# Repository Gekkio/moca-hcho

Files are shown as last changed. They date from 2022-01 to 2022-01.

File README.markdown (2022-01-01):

<!--
SPDX-FileCopyrightText: 2021-2022 Joonas Javanainen <joonas.javanainen@gmail.com>

SPDX-License-Identifier: CC0-1.0
-->

# moca-hcho: Bluetooth 5 BLE formaldehyde/temperature/humidity sensor beacon

moca-hcho is a simple Bluetooth Low Energy sensor beacon that uses a [Sensirion SFA30 Formaldehyde Sensor Module](https://www.sensirion.com/en/environmental-sensors/formaldehyde-sensor-sfa30/) to sense formaldehyde/temperature/humidity.
This information is measured and sent periodically using Bluetooth BLE advertisements, which can be received by any Bluetooth 4.0+ device within range.

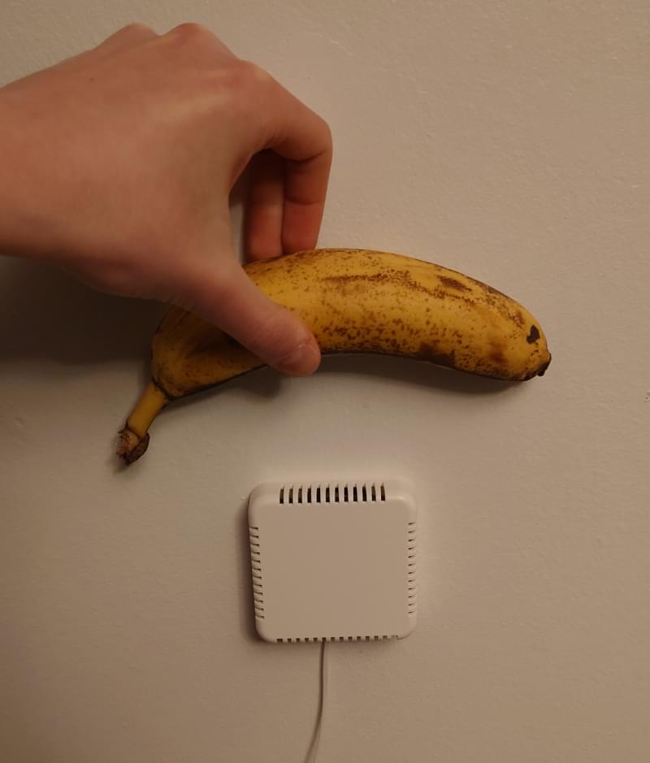
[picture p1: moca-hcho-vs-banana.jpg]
Wall-mounted moca-hcho with banana for scale


Overview:

* Enclosure: Hammond 1551V4WH vented sensor enclosure (wall-mountable)
* Sensor: Sensirion SFA30 Formaldehyde sensor module
* Microcontroller: Fanstel BT832 Bluetooth module with Nordic nRF52832
* Power supply: external +5V power supply
* Firmware (less than 1 kLOC) is written in [Rust](https://www.rust-lang.org/) using the [Embassy embedded async/await framework](https://github.com/embassy-rs/embassy)
* Data is sent periodically using Bluetooth BLE advertisements that are very simple to send and receive
* **Not FCC/Bluetooth/etc certified/qualified** but a "best effort" -style approach is used by using qualified BT832 module with integrated antenna + qualified Nordic S112 SoftDevice Bluetooth stack.

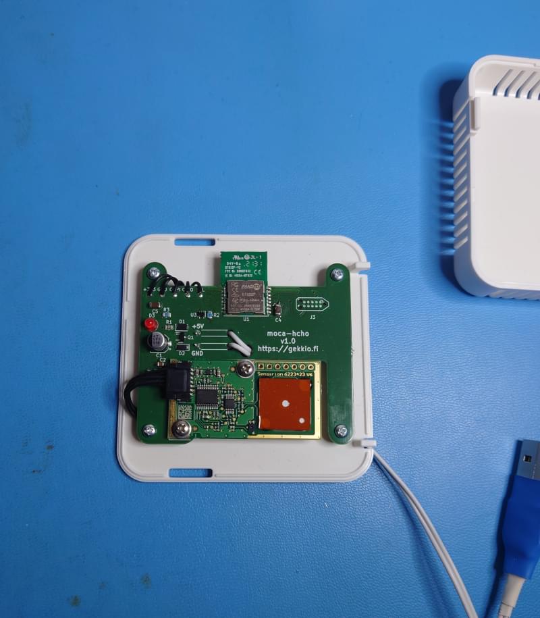
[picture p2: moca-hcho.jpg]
moca-hcho v1.0 assembled, without lid


## Potential future improvements

* Tidy up the code...currently the code is very crude and could use a lot of polish and some tests should be written
* Improve environmental coupling of the sensor. The vented enclosure works fine, but SFA30 Design-In Guide suggests even better environmental coupling options
* Add encryption. Unencrypted advertisements can be read or spoofed by anyone
* Re-evaluate the feasibility of using a battery

## License

Hardware is licensed under Creative Commons Attribution 4.0 International.

Firmware is licensed under either of

 * Apache License, Version 2.0, ([LICENSE-APACHE](LICENSE-APACHE) or http://www.apache.org/licenses/LICENSE-2.0)
 * MIT license ([LICENSE-MIT](LICENSE-MIT) or http://opensource.org/licenses/MIT)

at your option.

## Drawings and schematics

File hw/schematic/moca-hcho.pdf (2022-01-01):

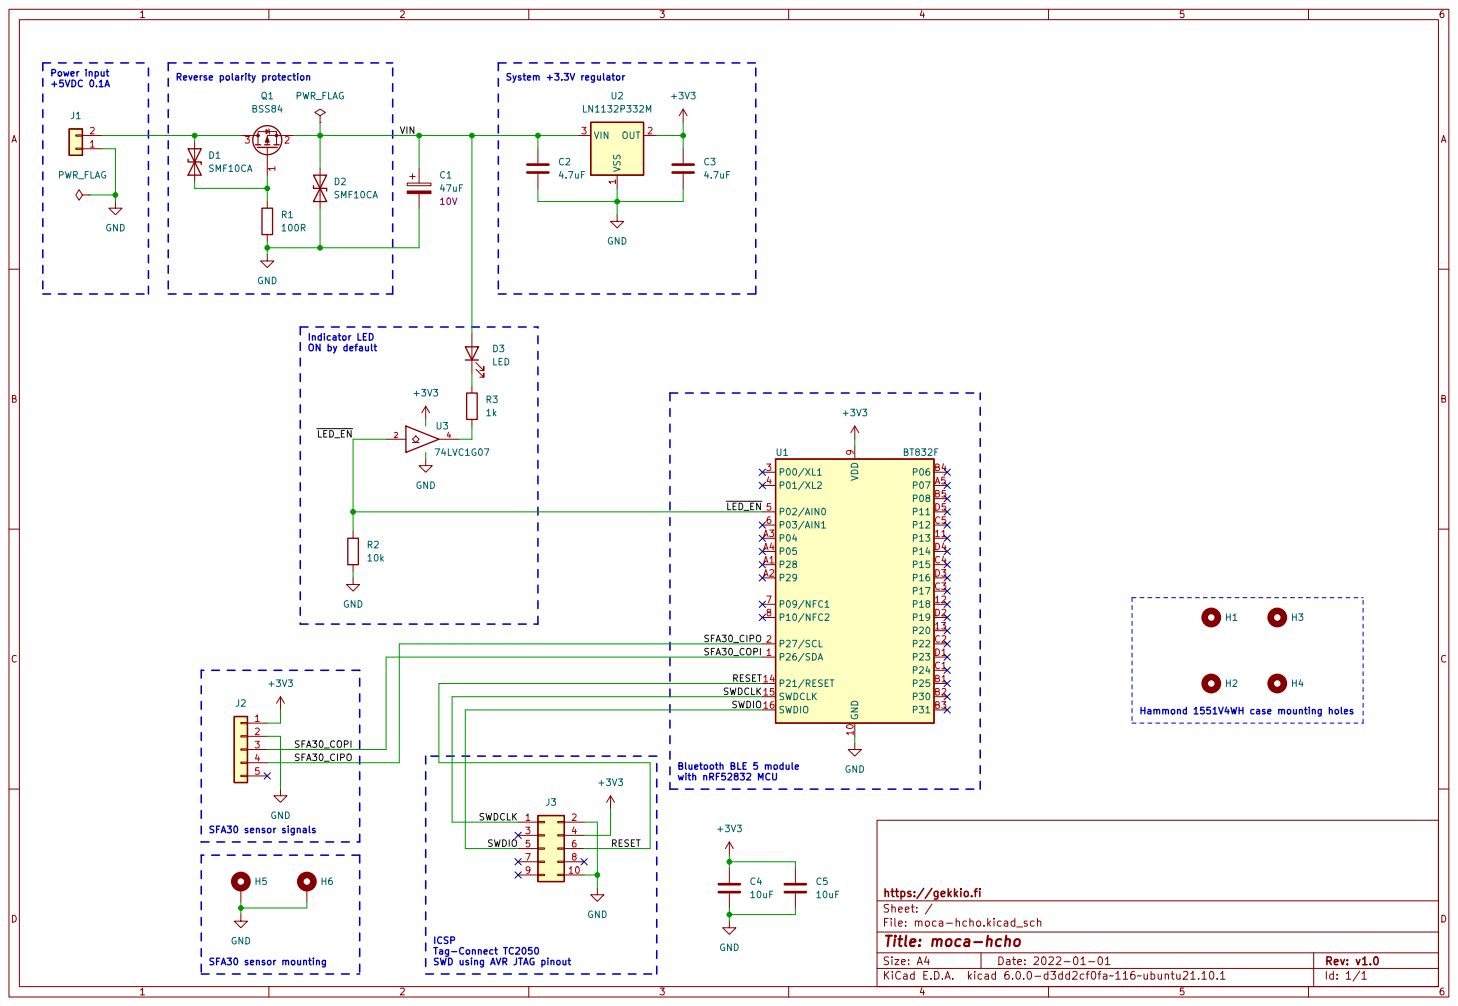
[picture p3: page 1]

System +3.3V regulator Power input +5VDC 0.1A

Indicator LED ON by default

Hammond 1551V4WH case mounting holes

5 | ICSP

File: moca-hcho.kicad_sch Sheet: / https://gekkio.fi H5

Id: 1/1 Title: moca-hcho

Tag-Connect TC2050
SWD using AVR JTAG pinout

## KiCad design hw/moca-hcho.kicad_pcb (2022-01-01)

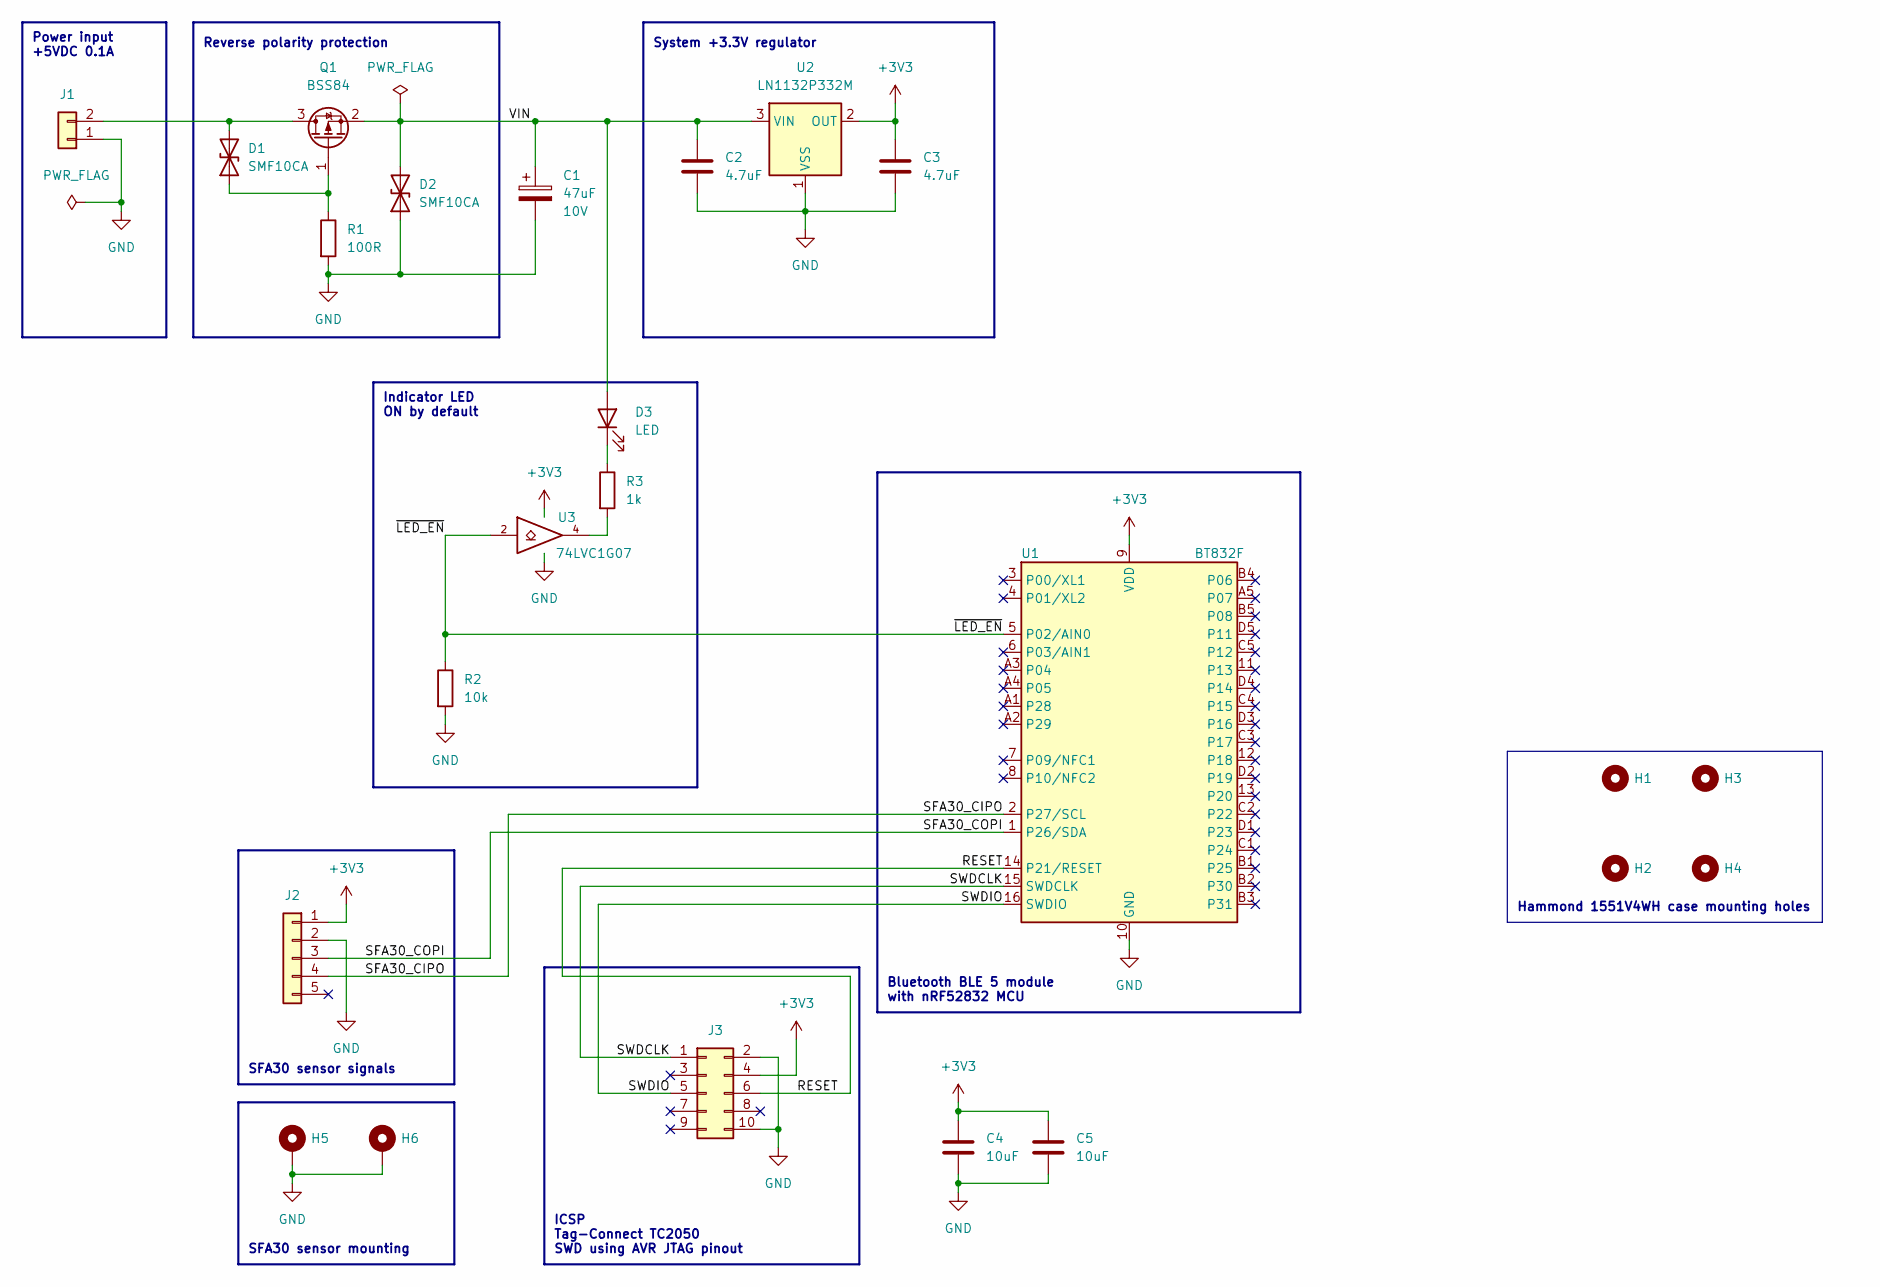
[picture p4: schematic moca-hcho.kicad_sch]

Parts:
C1: 47uF; CP_Elec_5x5.8; Rating 10V
C2, C3: 4.7uF; C_0805_2012Metric
C4, C5: 10uF; C_1206_3216Metric
D1, D2: SMF10CA; D_SOD-123F
D3: LED; LED_D3.0mm
H1, H2, H3, H4: DNP; MountingHole_2.5mm
H5, H6: DNP; MountingHole_2.7mm_M2.5_DIN965_Pad
J1: DNP; SolderWire-0.25sqmm_1x02_P4.2mm_D0.65mm_OD1.7mm_Relief
J2: DNP; SolderWire-0.15sqmm_1x05_P4mm_D0.5mm_OD1.5mm
J3: DNP; Tag-Connect_TC2050-IDC-NL_2x05_P1.27mm_Vertical
Q1: BSS84; SOT-23
R1: 100R; R_0805_2012Metric
R2: 10k; R_0805_2012Metric
R3: 1k; R_0805_2012Metric
U1: BT832F; Fanstel_BT832F
U2: LN1132P332M; SOT-23
U3: 74LVC1G07; SOT-353_SC-70-5

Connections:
+3V3: C3.1, C4.1, C5.1, J2.1, J3.4, U1.9 (VDD), U2.2 (OUT), U3.5 (VCC)
/RESET: J3.6, U1.14 (P21/RESET)
/SFA30_CIPO: J2.4, U1.2 (P27/SCL)
/SFA30_COPI: J2.3, U1.1 (P26/SDA)
/SWDCLK: J3.1, U1.15 (SWDCLK)
/SWDIO: J3.5, U1.16 (SWDIO)
/VIN: C1.1, C2.1, D2.2 (A2), D3.2 (A), Q1.2 (S), U2.3 (VIN)
/~LED_EN: R2.1, U1.5 (P02/AIN0), U3.2
GND: C1.2, C2.2, C3.2, C4.2, C5.2, D2.1 (A1), H5.1, H6.1, J1.1, J2.2, J3.2, J3.10, R1.2, R2.2, U1.10 (GND), U1.A0 (GND), U1.B0 (GND), U1.C0 (GND), U1.D0 (GND), U2.1 (VSS), U3.3 (GND)
unnamed: D1.1 (A1), Q1.1 (G), R1.1
unnamed: D1.2 (A2), J1.2, Q1.3 (D)
unnamed: D3.1 (K), R3.1
unnamed: R3.2, U3.4

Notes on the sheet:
System +3.3V regulator
Indicator LED ON by default
SFA30 sensor mounting
Reverse polarity protection
SFA30 sensor signals
Power input +5VDC 0.1A
Bluetooth BLE 5 module with nRF52832 MCU
Hammond 1551V4WH case mounting holes
ICSP Tag-Connect TC2050 SWD using AVR JTAG pinout

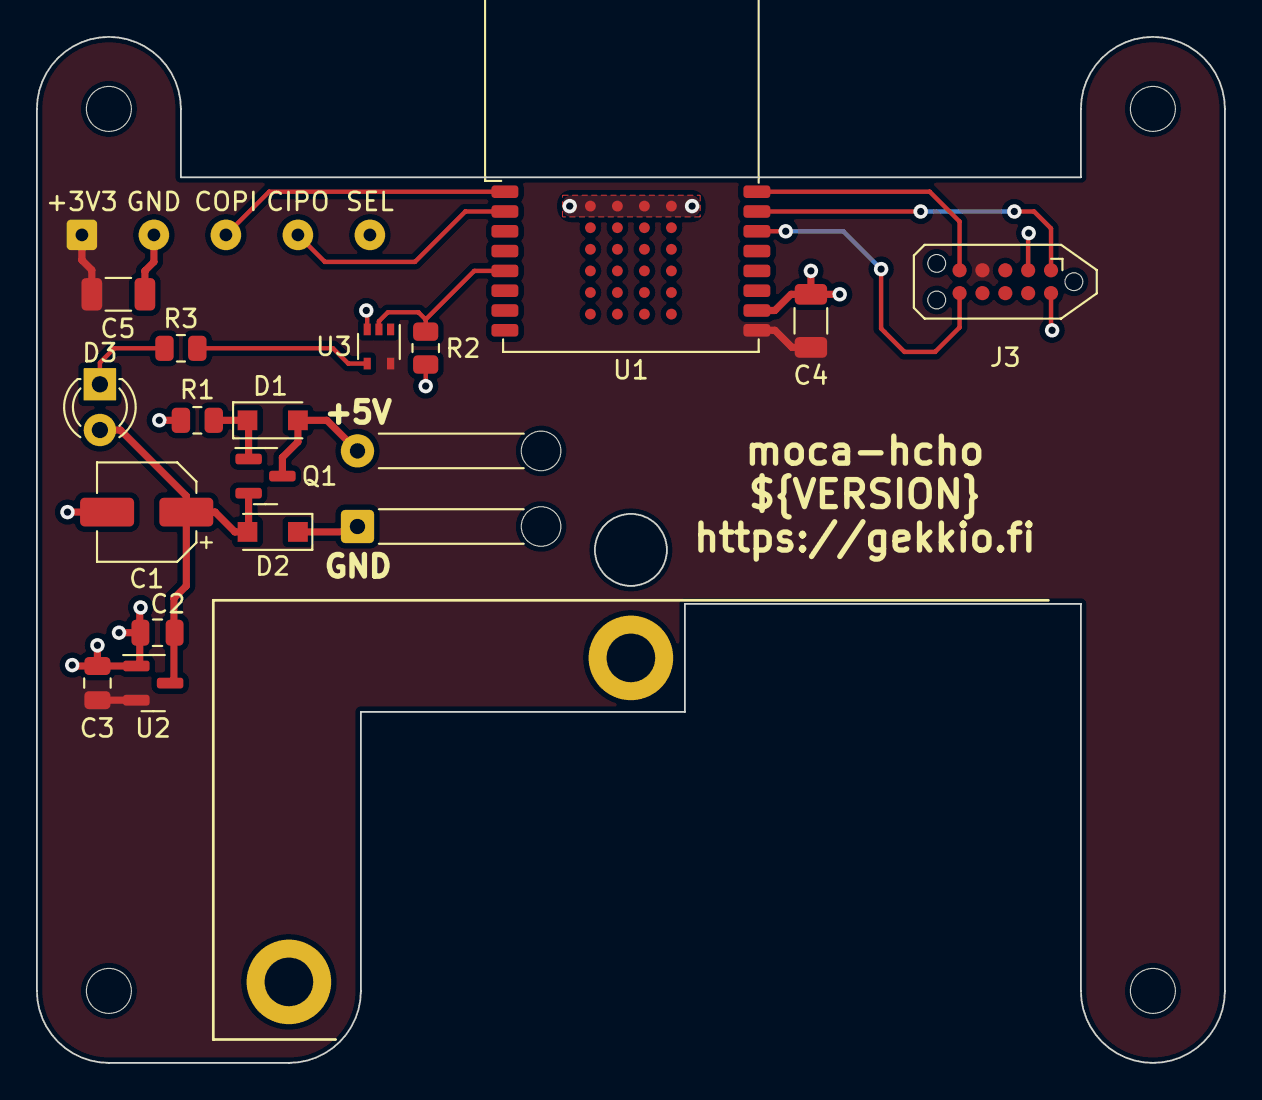
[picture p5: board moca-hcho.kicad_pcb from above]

Board: 2 copper layers, 66.0 x 57.0 mm, 24 parts (0 on the bottom side), 13 nets.

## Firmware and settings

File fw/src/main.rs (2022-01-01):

// SPDX-FileCopyrightText: 2021-2022 Joonas Javanainen <joonas.javanainen@gmail.com>
//
// SPDX-License-Identifier: MIT OR Apache-2.0

#![no_main]
#![no_std]
#![feature(type_alias_impl_trait)]
#![feature(alloc_error_handler)]

extern crate alloc;

use alloc::{string::String, vec::Vec};
use alloc_cortex_m::CortexMHeap;
use core::{
    alloc::Layout,
    borrow::Borrow,
    convert::Infallible,
    sync::atomic::{AtomicUsize, Ordering},
};
use defmt::{debug, error, info, unwrap, Format};
use embassy::{
    executor::{Executor, Spawner},
    time::{Duration, Timer},
    util::Forever,
};
use embassy_nrf::{
    self as _,
    config::HfclkSource,
    gpio::{Level, NoPin, Output, OutputDrive},
    interrupt::{self, Priority},
    peripherals::{P0_02, UARTE0},
    uarte::{self, Uarte},
    Peripherals,
};
use embassy_traits::uart::{Read, Write};
use embedded_hal::digital::v2::{OutputPin, StatefulOutputPin};
use futures::{join, pin_mut};
use moca_hcho::advertising::AdvertisingPayload;
use nrf_softdevice::{
    ble::{
        peripheral::{self, AdvertiseError},
        TxPower,
    },
    raw, Softdevice,
};
use nrf_softdevice_defmt_rtt as _;
use panic_probe as _;

const VENDOR_ID: u16 = 0xffff;
const LED_BLINKER_DURATION: Duration = Duration::from_secs(60 * 5);

#[global_allocator]
static ALLOCATOR: CortexMHeap = CortexMHeap::empty();
const ALLOCATOR_SIZE: usize = 4096;

// define what happens in an Out Of Memory (OOM) condition
#[alloc_error_handler]
fn alloc_error(layout: Layout) -> ! {
    panic!("Failed to allocate {} bytes", layout.size());
}

defmt::timestamp! {
    "{=u64}", {
        static COUNT: AtomicUsize = AtomicUsize::new(0);
        // NOTE(no-CAS) `timestamps` runs with interrupts disabled
        let n = COUNT.load(Ordering::Relaxed);
        COUNT.store(n + 1, Ordering::Relaxed);
        n as u64
    }
}

static EXECUTOR: Forever<Executor> = Forever::new();

#[embassy::task]
async fn softdevice_task(sd: &'static Softdevice) {
    debug!("Starting softdevice");
    sd.run().await;
}

type LedPin = P0_02;

struct Sfa30Buffer {
    data: [u8; 0x100],
    len: usize,
}

impl Default for Sfa30Buffer {
    fn default() -> Self {
        Sfa30Buffer {
            data: [0; 0x100],
            len: 0,
        }
    }
}

impl sfa30::ByteSink for Sfa30Buffer {
    type Error = sfa30::EncodeError;

    fn write_bytes(&mut self, bytes: &[u8]) -> Result<(), Self::Error> {
        self.data[self.len..(self.len + bytes.len())].copy_from_slice(bytes);
        self.len += bytes.len();
        Ok(())
    }
}

impl sfa30::ByteSource for Sfa30Buffer {
    type Error = Infallible;

    fn read_byte(&mut self) -> Result<u8, Self::Error> {
        let byte = self.data[self.len];
        self.len += 1;
        Ok(byte)
    }
}

#[derive(Copy, Clone, Debug, Eq, PartialEq, Format)]
struct Sfa30Measurement {
    hcho_concentration: i16,
    relative_humidity: i16,
    temperature: i16,
}

#[derive(Default)]
struct Sfa30 {
    read_buf: Vec<u8>,
}

impl Sfa30 {
    async fn write_command(
        &mut self,
        uart: &mut Uarte<'_, UARTE0>,
        cmd: u8,
        data: &[u8],
    ) -> Result<(), anyhow::Error> {
        let mut encoder = sfa30::Encoder::new(Sfa30Buffer::default());
        encoder
            .encode_command(cmd, data)
            .map_err(anyhow::Error::msg)?;
        let buf = encoder.finish();
        debug!("SFA W: {:02x}", &buf.data[..buf.len]);

        uart.write(&buf.data[..buf.len])
            .await
            .map_err(|_| anyhow::Error::msg("UART write error"))?;
        Ok(())
    }
    async fn read_response(
        &mut self,
        uart: &mut Uarte<'_, UARTE0>,
    ) -> Result<Vec<u8>, anyhow::Error> {
        self.read_buf.clear();
        self.read_buf.push(0x00);
        uart.read(&mut self.read_buf)
            .await
            .map_err(|_| anyhow::Error::msg("UART read error"))?;

        loop {
            let mut byte = [0x00];
            uart.read(&mut byte)
                .await
                .map_err(|_| anyhow::Error::msg("UART read error"))?;
            self.read_buf.push(byte[0]);
            if byte[0] == 0x7e {
                break;
            }
        }

        debug!("SFA R: {:02x}", &self.read_buf[..]);
        let mut buf = Sfa30Buffer::default();
        buf.data[..self.read_buf.len()].copy_from_slice(&self.read_buf);

        let mut decoder = sfa30::Decoder::new(buf);
        let mut output = Vec::new();
        decoder.decode_to(&mut output).map_err(anyhow::Error::msg)?;
        Ok(output)
    }
    pub async fn reset(&mut self, uart: &mut Uarte<'_, UARTE0>) -> Result<(), anyhow::Error> {
        self.write_command(uart, 0xd3, &[]).await?;
        let _ = self.read_response(uart).await?;
        Ok(())
    }
    pub async fn read_device_marking(
        &mut self,
        uart: &mut Uarte<'_, UARTE0>,
    ) -> Result<String, anyhow::Error> {
        self.write_command(uart, 0xd0, &[0x06]).await?;
        let mut output = self.read_response(uart).await?;
        let _ = output.pop();
        Ok(String::from_utf8(output).map_err(anyhow::Error::msg)?)
    }
    pub async fn start_measurement(
        &mut self,
        uart: &mut Uarte<'_, UARTE0>,
    ) -> Result<(), anyhow::Error> {
        self.write_command(uart, 0x00, &[0x00]).await?;
        self.read_response(uart).await?;
        Ok(())
    }
    pub async fn read_measurement(
        &mut self,
        uart: &mut Uarte<'_, UARTE0>,
    ) -> Result<Sfa30Measurement, anyhow::Error> {
        self.write_command(uart, 0x03, &[0x02]).await?;
        let data = self.read_response(uart).await?;
        Ok(Sfa30Measurement {
            hcho_concentration: i16::from_be_bytes([data[0], data[1]]),
            relative_humidity: i16::from_be_bytes([data[2], data[3]]),
            temperature: i16::from_be_bytes([data[4], data[5]]),
        })
    }
}

#[embassy::task]
async fn async_main(_spawner: Spawner, sd: &'static Softdevice, p: Peripherals) {
    let mut led: Output<LedPin> = Output::new(p.P0_02, Level::Low, OutputDrive::Standard);

    led.set_low().unwrap();

    let mut config = uarte::Config::default();
    config.parity = uarte::Parity::EXCLUDED;
    config.baudrate = uarte::Baudrate::BAUD115200;

    let irq = interrupt::take!(UARTE0_UART0);
    let mut uart = uarte::Uarte::new(p.UARTE0, irq, p.P0_27, p.P0_26, NoPin, NoPin, config);

    info!("uarte initialized!");

    Timer::after(Duration::from_secs(1)).await;

    let mut sfa = Sfa30::default();
    sfa.reset(&mut uart).await.unwrap();
    Timer::after(Duration::from_secs(1)).await;

    info!(
        "SFA30 marking: {}",
        sfa.read_device_marking(&mut uart).await.unwrap()
    );

    let led_timeout = Timer::after(LED_BLINKER_DURATION);
    let led_blinker = async move {
        let _ = led_blinker(led).await;
    };

    pin_mut!(led_timeout);
    pin_mut!(led_blinker);

    let measurement = measurement(sd, uart, sfa);
    let led = futures::future::select(led_timeout, led_blinker);

    join!(led, measurement);
}

async fn led_blinker(mut led: Output<'_, LedPin>) -> Result<(), Infallible> {
    led.set_high()?;
    loop {
        if led.is_set_high()? {
            led.set_low()?;
        } else {
            led.set_high()?;
        }
        Timer::after(Duration::from_millis(1000)).await;
    }
}

async fn measurement(sd: &'static Softdevice, mut uart: Uarte<'_, UARTE0>, mut sfa: Sfa30) {
    sfa.start_measurement(&mut uart).await.unwrap();

    loop {
        let tx_power = TxPower::ZerodBm;
        Timer::after(Duration::from_millis(10_000)).await;

        let meas = sfa.read_measurement(&mut uart).await.unwrap();
        debug!("Raw measurement: {:?}", meas);

        let mut packet = AdvertisingPayload::default();

        unwrap!(packet.push_ad_flags(raw::BLE_GAP_ADV_FLAGS_LE_ONLY_GENERAL_DISC_MODE as u8));
        unwrap!(packet.push_complete_name("moca-hcho"));
        unwrap!(packet.push_tx_power(tx_power));

        let mut custom = [0x00; 0x06];
        custom[0..2].copy_from_slice(&meas.hcho_concentration.to_be_bytes());
        custom[2..4].copy_from_slice(&meas.relative_humidity.to_be_bytes());
        custom[4..6].copy_from_slice(&meas.temperature.to_be_bytes());

        unwrap!(packet.push_manufacturer_data(VENDOR_ID, &custom));

        let config = peripheral::Config {
            max_events: Some(1),
            tx_power,
            ..Default::default()
        };
        let data: &[u8] = packet.borrow();
        let adv = peripheral::NonconnectableAdvertisement::NonscannableUndirected {
            adv_data: packet.borrow(),
        };
        match peripheral::advertise(sd, adv, &config).await {
            Ok(_) | Err(AdvertiseError::Timeout) => (),
            Err(err) => error!("{:?}", err),
        }

        debug!("BLE advertisement done");
    }
}

fn init_hal() -> Peripherals {
    let mut config = embassy_nrf::config::Config::default();
    config.hfclk_source = HfclkSource::ExternalXtal;
    config.gpiote_interrupt_priority = Priority::P7;
    config.time_interrupt_priority = Priority::P2;
    embassy_nrf::init(config)
}

fn enable_softdevice() -> &'static Softdevice {
    const CLOCK_SOURCE: u8 = raw::NRF_CLOCK_LF_SRC_RC as u8;
    const CALIBRATION_INTERVAL_4S: u8 = 16; // unit = 1/4 of seconds
    const TEMP_CALIBRATION_INTERVAL: u8 = 2; // unit = calibration intervals
    const CLOCK_ACCURACY: u8 = raw::NRF_CLOCK_LF_ACCURACY_500_PPM as u8;

    let config = nrf_softdevice::Config {
        clock: Some(raw::nrf_clock_lf_cfg_t {
            source: CLOCK_SOURCE,
            rc_ctiv: CALIBRATION_INTERVAL_4S,
            rc_temp_ctiv: TEMP_CALIBRATION_INTERVAL,
            accuracy: CLOCK_ACCURACY,
        }),
        ..Default::default()
    };

    Softdevice::enable(&config)
}

#[cortex_m_rt::entry]
fn main() -> ! {
    info!("Initializing global allocator");
    let start = cortex_m_rt::heap_start() as usize;
    unsafe { ALLOCATOR.init(start, ALLOCATOR_SIZE) }

    info!("Initializing HAL");
    let p = init_hal();

    info!("Enabling softdevice");
    let sd = enable_softdevice();

    let executor = EXECUTOR.put(Executor::new());
    info!("Starting system executor");
    executor.run(|spawner| {
        unwrap!(spawner.spawn(softdevice_task(sd)));
        unwrap!(spawner.spawn(async_main(spawner, sd, p)));
    });
}

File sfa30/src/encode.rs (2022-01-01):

// SPDX-FileCopyrightText: 2021-2022 Joonas Javanainen <joonas.javanainen@gmail.com>
//
// SPDX-License-Identifier: MIT OR Apache-2.0

use core::fmt;
#[cfg(feature = "std")]
use std::io::{self, Write};

#[derive(Copy, Clone, Debug)]
pub enum EncodeError {
    DataLengthOverflow,
}

impl fmt::Display for EncodeError {
    fn fmt(&self, f: &mut fmt::Formatter) -> fmt::Result {
        match self {
            EncodeError::DataLengthOverflow => write!(f, "data length overflow"),
        }
    }
}

pub trait ByteSink {
    type Error: From<EncodeError>;
    fn write_byte(&mut self, byte: u8) -> Result<(), Self::Error> {
        self.write_bytes(&[byte])
    }
    fn write_bytes(&mut self, bytes: &[u8]) -> Result<(), Self::Error>;
}

#[cfg(feature = "std")]
impl std::error::Error for EncodeError {}

#[cfg(feature = "std")]
impl From<EncodeError> for io::Error {
    fn from(err: EncodeError) -> Self {
        match err {
            EncodeError::DataLengthOverflow => io::Error::new(io::ErrorKind::Other, err),
        }
    }
}

#[cfg(feature = "std")]
impl<T> ByteSink for T
where
    T: Write,
{
    type Error = io::Error;

    fn write_bytes(&mut self, bytes: &[u8]) -> Result<(), Self::Error> {
        self.write_all(bytes)?;
        Ok(())
    }
}

#[derive(Copy, Clone, Debug)]
pub struct Encoder<S: ByteSink> {
    sink: S,
}

impl<S: ByteSink> Encoder<S> {
    pub fn new(sink: S) -> Encoder<S> {
        Encoder { sink }
    }
    fn write_byte(&mut self, byte: u8) -> Result<(), S::Error> {
        match byte {
            // Reference: SFA30 Data Sheet - Table 9: Reference table for byte-stuffing
            0x7e => self.sink.write_bytes(&[0x7d, 0x5e]),
            0x7d => self.sink.write_bytes(&[0x7d, 0x5d]),
            0x11 => self.sink.write_bytes(&[0x7d, 0x31]),
            0x13 => self.sink.write_bytes(&[0x7d, 0x33]),
            _ => self.sink.write_byte(byte),
        }
    }
    fn write_frame_byte(&mut self, checksum: &mut u8, byte: u8) -> Result<(), S::Error> {
        self.write_byte(byte)?;
        *checksum = checksum.wrapping_add(byte);
        Ok(())
    }
    pub fn encode_command(&mut self, cmd: u8, data: &[u8]) -> Result<(), S::Error> {
        let len: u8 = data
            .len()
            .try_into()
            .map_err(|_| EncodeError::DataLengthOverflow)?;
        // Reference: SFA30 Data Sheet - 4.2 SHDLC Frame Layer
        const START: u8 = 0x7e;
        const ADR: u8 = 0x00;
        const STOP: u8 = 0x7e;
        self.sink.write_byte(START)?;
        let mut checksum = 0x00;
        self.write_frame_byte(&mut checksum, ADR)?;
        self.write_frame_byte(&mut checksum, cmd)?;
        self.write_frame_byte(&mut checksum, len)?;
        for &byte in data {
            self.write_frame_byte(&mut checksum, byte)?;
        }
        checksum = !checksum;
        self.sink.write_byte(checksum)?;
        self.sink.write_byte(STOP)
    }
    pub fn finish(self) -> S {
        self.sink
    }
}

#[test]
fn test_encode() {
    let mut buffer = Vec::new();
    let mut encoder = Encoder::new(&mut buffer);
    encoder.encode_command(0x00, &[0x01, 0x01]).unwrap();
    assert_eq!(
        &buffer[..],
        &[0x7e, 0x00, 0x00, 0x02, 0x01, 0x01, 0xfb, 0x7e]
    );
}
